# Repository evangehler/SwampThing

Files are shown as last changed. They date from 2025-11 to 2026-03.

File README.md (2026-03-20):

# **SwampThing**
Beginning of a standalone Juno-106 inspired DCO monosynth for UF AES. Built around Raspberry Pi Pico Microcontroller.

## **Project Status**
| Component | Designed  | Prototyped  | PCB / Finalized |
| ----- | ---  | --- | --- |
| DCO Saw-core | X | X | |
| DCO Pulse / PWM | X | X | |
| DCO SUB | X | | |
| Blend | X | | |
| MIDI USB | X | X | |
| MIDI DIN | X | X | |
| VCF | X | X | |
| EG | X | X | |
| VCA | X | X | |
| Power Solution | | | |
| Output | | | |

# Table of Contents
- [Installation / Build](#installation--build)
  - [Prereqs](#prereqs)
  - [Build Steps](#build-steps)
  - [Quick Build & Flash](#quick-build--flash)
  - [Manual Flashing](#manual-flashing)
  - [I/O Notes](#io-notes)
- [Architecture](#architecture)
  - [Component Diagram](#component-diagram)
  - [MIDI](#midi)
    - [USB MIDI](#usb-midi-implemented)
    - [DIN MIDI](#din-midi-planned)
  - [Digitally Controlled Oscillator (DCO)](#digitally-controlled-oscillator-dco)
    - [SAW](#saw)
    - [PULSE / PWM](#pulse--pwm)
    - [SUB OSC](#sub-osc)
    - [BLEND](#blend)
  - [Envelope Generator (EG)](#envelope-generator-eg)
  - [Voltage Controlled Amplifier (VCA)](#voltage-conrolled-amplifier-vca)
  - [Voltage Controlled Filter (VCF)](#voltage-controlled-filter-vcf)
  - [Power Solution](#power-solution)
- [Incomplete BOM](#incomplete-bom)

# Installation / Build
MIDI control, oscillator reset signals, charge voltage and envelope gates are derived from a Raspberry Pi Pico.

### Prereqs
- [VS Code](https://code.visualstudio.com/)
- [Raspberry Pi Pico VS Code Extension](https://marketplace.visualstudio.com/items?itemName=raspberry-pi.raspberry-pi-pico)

### Build Steps
1. Clone this repo
2. Open the `src` folder in VS Code (not the root folder!)
3. Open a PowerShell terminal in VS Code
4. Run:
```powershell
mkdir build
cd build
cmake -G "Ninja" ..
cmake --build .
```
5. The `.uf2` file will be in `build/SwampThing.uf2`

### Quick Build & Flash
- Press `Ctrl+Shift+B` to build and flash in one step - nifty!

### Manual Flashing
1. Hold BOOTSEL on your Pico and plug it in
2. Drag `SwampThing.uf2` onto the Pico drive

### I/O Notes:

| Function | GPIO # | 
| ----- | --- |
| Clock output | 13 |
| CV output | 14 |
| Gate output | 12 |

# Architecture
## Component Diagram:
Component Diagram

## MIDI:

### USB MIDI (Implemented)
SwampThing appears as a **class-compliant USB MIDI device** over the Pico’s micro-USB port using TinyUSB.

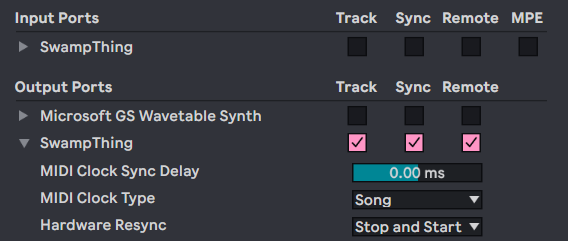
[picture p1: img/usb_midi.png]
USB_MIDI USB MIDI


### DIN MIDI (Planned)

5-pin DIN MIDI IN (with opto-isolation and UART at 31.25 kbps) is planned. DIN and USB MIDI will eventually share the same internal note/gate handling.

## Digitally Controlled Oscillator (DCO):
Basic DCO
### SAW
Juno-style ramp core. A TL074 op-amp integrator generates a rising ramp, NPN transistor reset discharges the timing capacitor at a rate set by the microcontroller clock. Pitch is set by the reset clock (GPIO 13). Ramp slope is set by a PWM-derived charge voltage filtered to DC (GPIO 14).

### PULSE / PWM
Saw --> Comparator, threshold = PWM

### SUB OSC
OSC --> Flip Flop, halves frequency

### BLEND
Blend control between saw and pwm

## Envelope Generator (EG):
*Currently In Development*

Design chosen

## Voltage Conrolled Amplifier (VCA):
*Currently In Development*

JFET implementation

## Voltage Controlled Filter (VCF):
*Currently In Development*

Based on Mortiz Klein / Erica Synths VCF

## Power Solution:
*Currently In Development*

 Presently planning +/- 12V, 5V rails.

 ## Prototype:
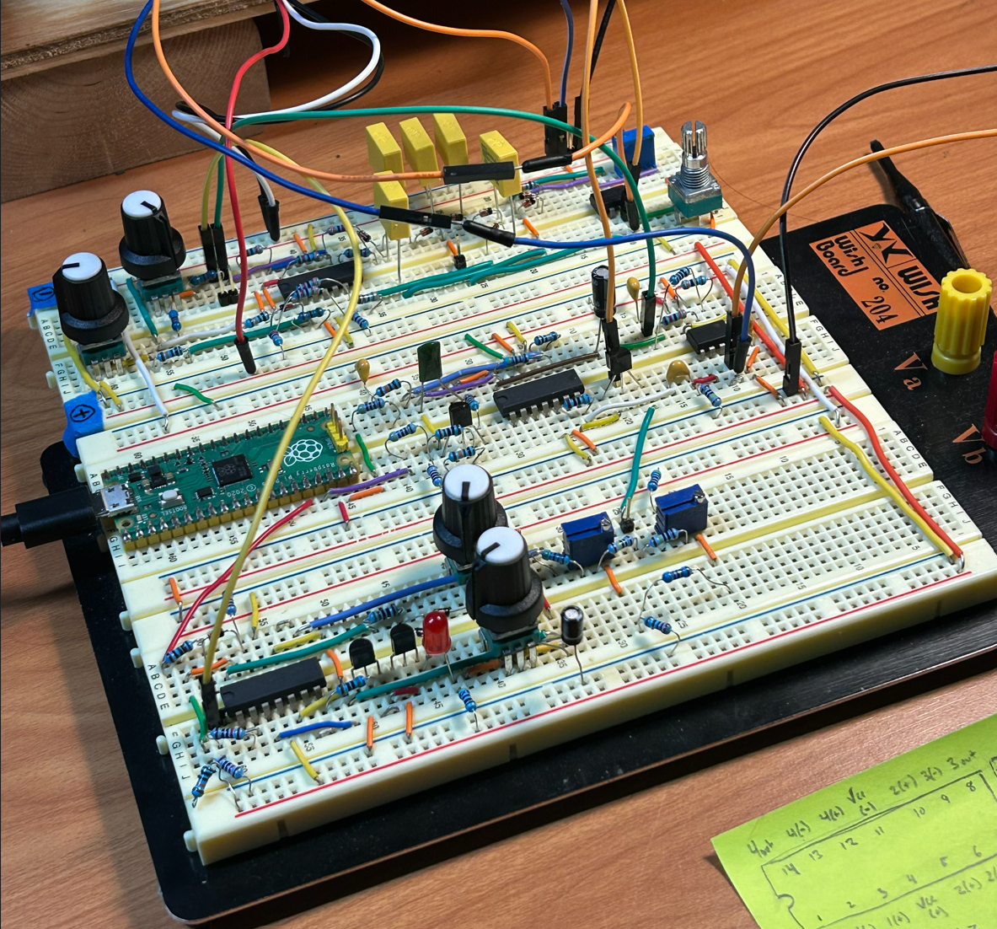
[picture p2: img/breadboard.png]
Prototype


# Incomplete BOM:

| PART | QTY | NOTE |
| ----- | ---  | --- |
| Raspberry Pi Pico | 1 | Micrcontroller |
| TL074 | 1 | 4x Op Amp |
| 2N3904 NPN BJT | 1 | Reset Transistor  |

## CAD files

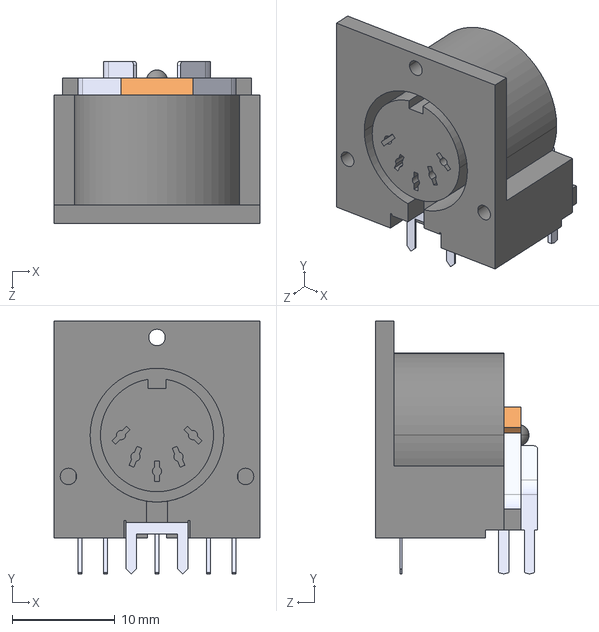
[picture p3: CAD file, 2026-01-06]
sims/Julian_kicad/Swamp_thing_V0/external components/SDS-50J/SDS-50J.step
20.0 x 24.6 x 15.8 mm

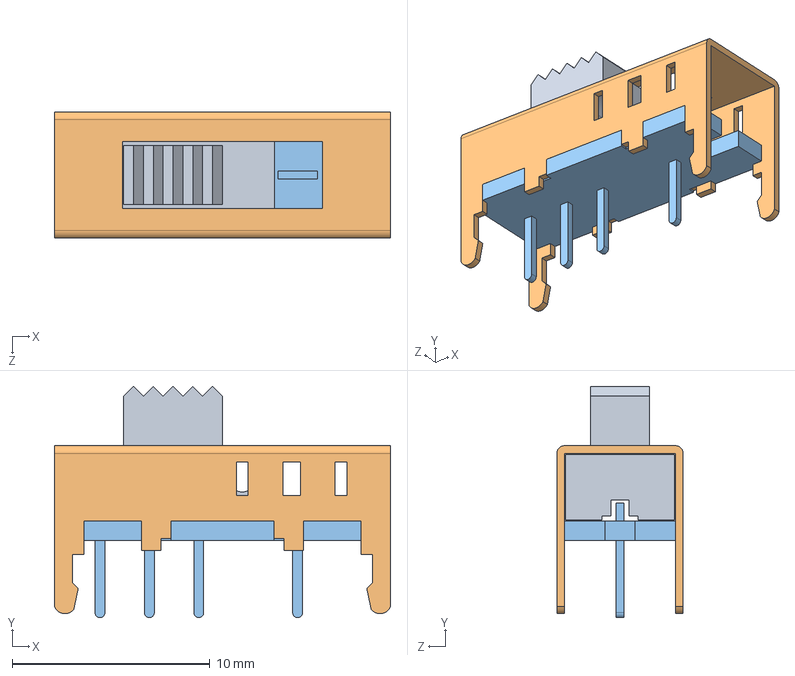
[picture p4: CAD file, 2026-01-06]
sims/Julian_kicad/Swamp_thing_V0/external components/SLW-178562-3A-S-D/SLW-178562-3A-S-D.step
17.0 x 11.7 x 6.40 mm

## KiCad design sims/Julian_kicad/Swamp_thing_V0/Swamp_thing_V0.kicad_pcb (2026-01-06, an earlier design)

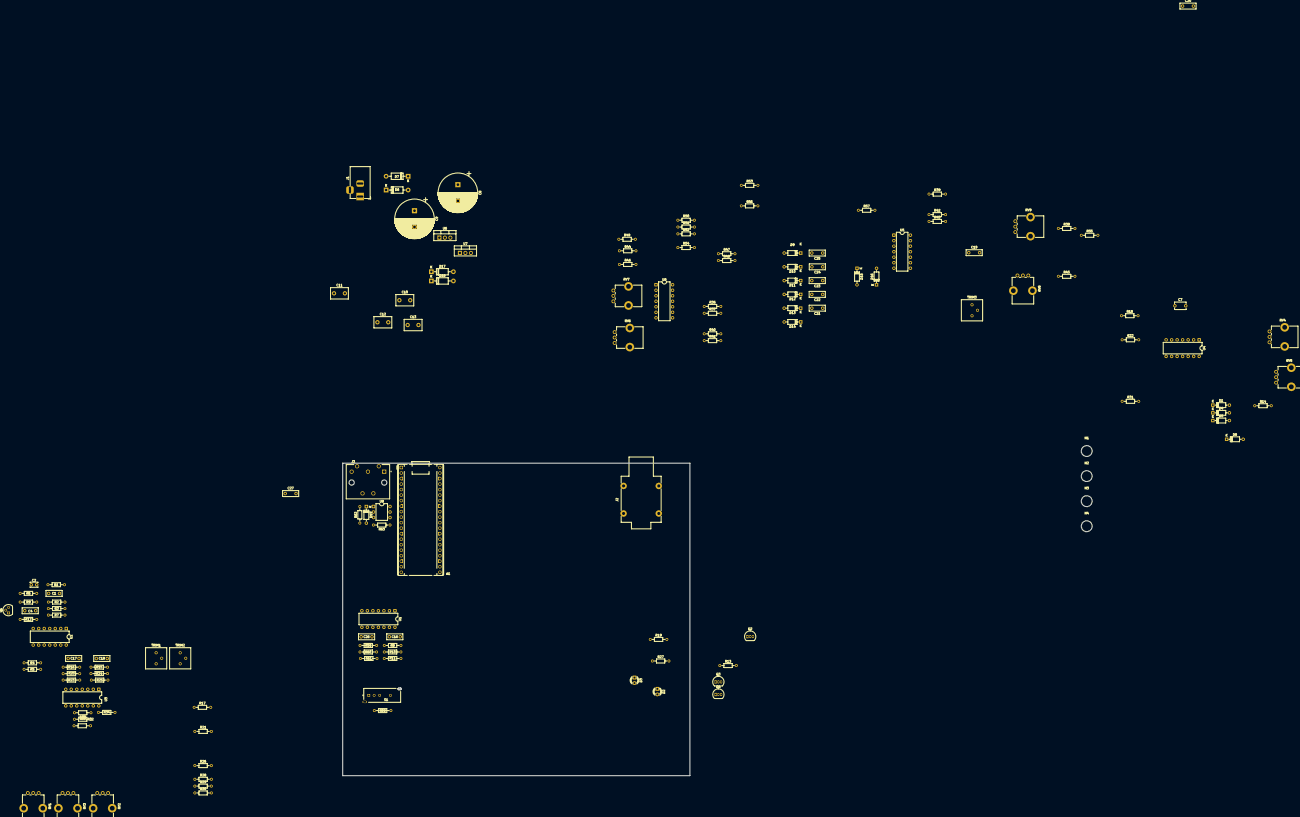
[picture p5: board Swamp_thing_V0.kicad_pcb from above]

Board: 2 copper layers, 160.0 x 144.0 mm, 138 parts (0 on the bottom side), 107 nets, no tracks yet.

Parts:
A1: RaspberryPi_Pico; RaspberryPi_Pico_Common_THT
C1, C16, C17, C18, C19, C20, C26, C27: 100n; C_Rect_L7.2mm_W2.5mm_P5.00mm_FKS2_FKP2_MKS2_MKP2
C2: 470pF; C_Disc_D3.4mm_W2.1mm_P2.50mm
C4, C21, C22, C23, C24, C25: 1n; C_Rect_L7.2mm_W2.5mm_P5.00mm_FKS2_FKP2_MKS2_MKP2
C7: C; C_Disc_D5.1mm_W3.2mm_P5.00mm
C8, C9: 3300uF; CP_Radial_D18.0mm_P7.50mm
C10, C11, C12, C13: C; C_Disc_D8.0mm_W5.0mm_P5.00mm
D1, D4, D5, D8, D9, D10, D11, D12, D13, D14, D15, D16, D19: 1N4148; D_DO-35_SOD27_P7.62mm_Horizontal
D2, D3: LED; LED_D3.0mm
D6, D7, D17, D18: 1N4007; D_DO-41_SOD81_P10.16mm_Horizontal
H1, H2, H3, H4: MountingHole; MountingHole_5mm
J1: Barrel_Jack_MountingPin; BarrelJack_Horizontal
J2: NMJ4HFD2; Jack_6.35mm_Neutrik_NMJ4HFD2_Horizontal
J3: SDS-50J; CUI_SDS-50J
Q1: 2N3904; TO-92
Q2, Q3, Q4: 2N3904; TO-92_Inline
R1, R2, R3, R4, R5, R6, R7, R8, R9, R10, R11, R12, R13, R14, R15, R16, R17, R18, R19, R20, R21, R22, R23, R24, R25, R26, R27, R28, R29, R30, R31, R32, R33, R34, R35, R36, R37, R38, R39, R40, R41, R42, R43, R44, R45, R46, R47, R48, R49, R50, R51, R52, R53, R54, R55, R56, R57, R58, R59, R60, R61: R_US; R_Axial_DIN0204_L3.6mm_D1.6mm_P7.62mm_Horizontal
R62: 220; R_Axial_DIN0204_L3.6mm_D1.6mm_P7.62mm_Horizontal
R63: 180; R_Axial_DIN0204_L3.6mm_D1.6mm_P7.62mm_Horizontal
RV1: PWM; Potentiometer_Bourns_PTV09A-1_Single_Vertical
RV2: BLEND; Potentiometer_Bourns_PTV09A-1_Single_Vertical
RV3: SUB VOL; Potentiometer_Bourns_PTV09A-1_Single_Vertical
RV4: ATTACK; Potentiometer_Bourns_PTV09A-1_Single_Vertical
RV5: RELEASE; Potentiometer_Bourns_PTV09A-1_Single_Vertical
RV6: FILTER; Potentiometer_Bourns_PTV09A-1_Single_Vertical
RV7: FILTER EG; Potentiometer_Bourns_PTV09A-1_Single_Vertical
RV8: VOLUME; Potentiometer_Bourns_PTV09A-1_Single_Vertical
RV9: RESO; Potentiometer_Bourns_PTV09A-1_Single_Vertical
S1: SLW-178562-3A-S-D; SW_SLW-178562-3A-S-D
TRIM1, TRIM2, TRIM3: R_Potentiometer_Trim_US; Potentiometer_Bourns_3386P_Vertical
U1: 4013; DIP-14_W7.62mm
U2, U3, U4, U5, U8: TL074; DIP-14_W7.62mm
U6: L7812; TO-220-3_Vertical
U7: L7912; TO-220-3_Vertical
U9: H11L1; DIP-6_W7.62mm

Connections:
+3V3: A1.36 (3V3), R63.2, U9.6
+12V: C11.2, D17.2 (A), R4.1, R18.2, R19.2, R27.2, RV6.1, U1.14 (VDD), U2.4 (V+), U3.4 (V+), U4.4 (V+), U5.4 (V+), U6.3 (OUT), U8.4 (V+)
-12V: C13.1, D18.1 (K), R28.2, R36.1, R46.1, U2.11 (V-), U3.11 (V-), U4.11 (V-), U5.11 (V-), U7.3 (VO), U8.11 (V-)
/CLK: A1.19 (GPIO14), C2.2
/Charge PWM: A1.20 (GPIO15), R1.2
/EG_TO_LED: R13.2, U4.8, U4.9 (-)
/EG_TO_VCA: R17.2, U4.13 (-), U4.14
/EG_TO_VCF: R37.2, U4.6 (-), U4.7
/FILTER_FB: C21.1, C25.1, D15.2 (A), D16.1 (K), R57.2, U5.7
/JFET_BIAS: R21.1, R26.2
/MIDI_DIN_IN: R63.1, U9.4
/N_SUB-1: U1.2 (~Q), U1.5 (D)
/N_SUB-2: U1.9 (D), U1.12 (~Q)
/PULSE: C17.1, U2.8
/SAW: C4.2, C18.1, R12.1, U2.7, U2.9 (-)
/SUB: RV3.1, RV3.2, U2.13 (-), U2.14
/SUB-1: C26.1, U1.1 (Q), U1.11 (C)
/SUB-2: C16.1, U1.13 (Q)
/VCA_OUT: C19.1, R34.2, U3.14
/VCF_AUDIO: R47.2, R50.1, U8.1, U8.2 (-)
/VCF_BIAS: D8.1 (K), R46.2, R48.2, R49.1, R51.1
/VCF_OUT: R38.1, RV9.3, U5.1, U5.2 (-)
GND: A1.3 (GND), A1.8 (GND), A1.13 (GND), A1.18 (GND), A1.23 (GND), A1.28 (GND), A1.38 (GND), C1.2, C7.2, C8.2, C9.1, C10.1, C11.1, C12.2, C13.2, C22.1, C23.1, C24.1, C27.1, J1.2, J2.S, Q2.1 (E), Q3.1 (E), Q4.1 (E), R5.2, R6.1, R11.1, R22.2, R23.1, R25.2, R30.1, R43.1, R45.2, R49.2, R52.2, R59.2, R61.1, RV7.3, U1.4 (R), U1.6 (S), U1.7 (VSS), U1.8 (S), U1.10 (R), U2.3 (+), U2.5 (+), U3.10 (+), U3.12 (+), U5.10 (+), U6.2 (GND), U7.1 (GND), U8.5 (+), U8.10 (+), U9.5
unnamed: C1.1, R1.1, R2.2
unnamed: C2.1, R6.2, R9.2
unnamed: C16.2, R8.2
unnamed: C17.2, R16.2
unnamed: C18.2, R15.2
unnamed: C19.2, R39.2
unnamed: C20.1, RV8.2, RV8.3, U5.8
unnamed: C26.2, R58.2
unnamed: C27.2, J3.2
unnamed: D1.2 (A), R14.1
unnamed: D1.1 (K), U4.3 (+)
unnamed: D2.2 (A), R19.1
unnamed: D2.1 (K), Q3.3 (C)
unnamed: D3.2 (A), R27.1
unnamed: D3.1 (K), Q4.3 (C)
unnamed: D4.2 (A), D5.1 (K), R31.1
unnamed: D4.1 (K), RV4.3
unnamed: D5.2 (A), RV5.3
unnamed: D6.1 (K), D7.2 (A), J1.1
unnamed: D8.2 (A), R44.2, U8.7
unnamed: D9.2 (A), R53.1, R56.2
unnamed: C25.2, D9.1 (K), D10.2 (A)
unnamed: C24.2, D10.1 (K), D11.2 (A)
unnamed: C23.2, D11.1 (K), D12.2 (A), U5.3 (+)
unnamed: C22.2, D12.1 (K), D13.2 (A)
unnamed: C21.2, D13.1 (K), D14.2 (A)
unnamed: D14.1 (K), R54.2, U8.14
unnamed: D15.1 (K), D16.2 (A), R57.1, TRIM3.1, TRIM3.2, U5.6 (-)
unnamed: C8.1, C10.2, D7.1 (K), D17.1 (K), U6.1 (IN)
unnamed: C9.2, C12.1, D6.2 (A), D18.2 (A), U7.2 (VI)
unnamed: D19.2 (A), R62.1, U9.2
unnamed: D19.1 (K), J3.4, U9.1
unnamed: J2.T, R55.2
unnamed: J3.5, R62.2
unnamed: Q1.2 (B), R9.1
unnamed: Q1.3 (C), R12.2
unnamed: C4.1, Q1.1 (E), R7.1, U2.6 (-)
unnamed: Q2.2 (B), Q2.3 (C), Q3.2 (B), Q4.2 (B), R13.1
unnamed: R34.1, U3.13 (-)
unnamed: R3.1, R7.2, U2.1
unnamed: R4.2, RV1.1
unnamed: R5.1, RV1.3
unnamed: R10.1, R11.2
unnamed: R8.1, R10.2, S1.4
unnamed: R16.1, R20.2
unnamed: R17.1, TRIM1.1
unnamed: R21.2, TRIM1.2
unnamed: R24.2, R25.1
unnamed: R26.1, TRIM2.2
unnamed: R28.1, TRIM2.1
unnamed: R29.1, R30.2, TRIM1.3
unnamed: R29.2, TRIM2.3
unnamed: R31.2, U4.1
unnamed: R32.2, RV2.2
unnamed: R33.2, RV3.3
unnamed: R36.2, RV6.3
unnamed: R37.1, RV7.1
unnamed: R39.1, R42.2
unnamed: R40.1, RV6.2
unnamed: R41.1, RV7.2
unnamed: R56.1, U8.8
unnamed: R58.1, R60.2, S1.1
unnamed: R59.1, S1.2
unnamed: R60.1, R61.2
unnamed: RV9.1, TRIM3.3
unnamed: R2.1, R3.2, U2.2 (-)
unnamed: RV1.2, U2.10 (+)
unnamed: S1.3, U2.12 (+)
unnamed: R15.1, R24.1, U3.3 (+)
unnamed: RV2.1, U3.1, U3.2 (-)
unnamed: R20.1, R23.2, U3.5 (+)
unnamed: RV2.3, U3.6 (-), U3.7
unnamed: R32.1, R33.1, R35.2, U3.9 (-)
unnamed: R18.1, R22.1, U4.2 (-)
unnamed: C7.1, RV4.1, RV4.2, RV5.1, RV5.2, U4.5 (+), U4.10 (+), U4.12 (+)
unnamed: RV9.2, U5.5 (+)
unnamed: R38.2, RV8.1, U5.9 (-)
unnamed: C20.2, R45.1, U5.12 (+)
unnamed: R55.1, U5.13 (-), U5.14
unnamed: R42.1, R43.2, U8.3 (+)
unnamed: R40.2, R41.2, R44.1, U8.6 (-)
unnamed: R47.1, R48.1, R53.2, U8.9 (-)
unnamed: R51.2, R52.1, U8.12 (+)
unnamed: R50.2, R54.1, U8.13 (-)

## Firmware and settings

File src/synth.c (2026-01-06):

#include "synth.h"
#include "pico/stdlib.h"
#include "hardware/pwm.h"

// ---------------- Pins ----------------
#define CLOCK_PIN 13
#define CV_PIN    14
#define GATE_PIN  12

// ---------------- Clocks/rails ----------------
#define SYS_CLK_HZ 125000000.0f
#define V_SUPPLY   3.3f
#define V_SUPPLY_INV (1.0f / V_SUPPLY)

// ---------------- Clocked-reset DCO model ----------------
#define CLOCK_DIV     150.0f
#define CLOCK_DIV_INV (1.0f / CLOCK_DIV)
#define RESET_US      9.0f

// Pre-compute tick rate and reset pulse width
#define TICK_HZ       (SYS_CLK_HZ * CLOCK_DIV_INV)
#define RESET_TICKS   ((uint32_t)(TICK_HZ * RESET_US * 1e-6f + 0.5f))

// CV mapping
#define MV_PER_HZ     0.000060f
#define CV_GAIN       10.0f
#define CV_OFFSET     0.0f

// CV PWM carrier
#define CV_PWM_CARRIER_HZ 500000u

// Frequency limits
#define FREQ_MIN      10.0f
#define FREQ_MAX      20000.0f

// ---------------- Static state ----------------
static uint clk_slice, clk_chan;
static uint cv_slice,  cv_chan;
static uint32_t cv_wrap = 0;

void synth_init(void) {
    // ----- RESET CLOCK PWM -----
    gpio_set_function(CLOCK_PIN, GPIO_FUNC_PWM);
    clk_slice = pwm_gpio_to_slice_num(CLOCK_PIN);
    clk_chan  = pwm_gpio_to_channel(CLOCK_PIN);

    pwm_config clk_cfg = pwm_get_default_config();
    pwm_config_set_clkdiv(&clk_cfg, CLOCK_DIV);
    pwm_config_set_wrap(&clk_cfg, 60000);
    pwm_init(clk_slice, &clk_cfg, true);
    pwm_set_chan_level(clk_slice, clk_chan, 1);

    // ----- CV PWM -----
    gpio_set_function(CV_PIN, GPIO_FUNC_PWM);
    cv_slice = pwm_gpio_to_slice_num(CV_PIN);
    cv_chan  = pwm_gpio_to_channel(CV_PIN);

    // Compute wrap for carrier frequency
    cv_wrap = (uint32_t)(SYS_CLK_HZ / CV_PWM_CARRIER_HZ) - 1;

    pwm_config cv_cfg = pwm_get_default_config();
    pwm_config_set_clkdiv(&cv_cfg, 1.0f);
    pwm_config_set_wrap(&cv_cfg, cv_wrap);
    pwm_init(cv_slice, &cv_cfg, true);
    pwm_set_chan_level(cv_slice, cv_chan, 0);

    // ----- GATE -----
    gpio_init(GATE_PIN);
    gpio_set_dir(GATE_PIN, GPIO_OUT);
    gpio_put(GATE_PIN, 0);
}

void synth_set_frequency(float freq_hz) {
    // Clamp frequency
    if (freq_hz < FREQ_MIN) freq_hz = FREQ_MIN;
    else if (freq_hz > FREQ_MAX) freq_hz = FREQ_MAX;

    // ---------- RESET CLOCK ----------
    float wrap_f = (SYS_CLK_HZ * CLOCK_DIV_INV / freq_hz) - 1.0f;
    
    // Clamp wrap value
    if (wrap_f < 1.0f) wrap_f = 1.0f;
    else if (wrap_f > 65535.0f) wrap_f = 65535.0f;
    
    uint16_t wrap = (uint16_t)(wrap_f + 0.5f);
    pwm_set_wrap(clk_slice, wrap);

    // ---------- RESET PULSE ----------
    // Using pre-computed constant, clamp to wrap
    uint32_t pulse = (RESET_TICKS > wrap) ? wrap : RESET_TICKS;
    pwm_set_chan_level(clk_slice, clk_chan, pulse);

    // ---------- CV ----------
    float v_cv = (freq_hz * MV_PER_HZ) * CV_GAIN + CV_OFFSET;
    
    // Clamp voltage
    if (v_cv < 0.0f) v_cv = 0.0f;
    else if (v_cv > V_SUPPLY) v_cv = V_SUPPLY;

    // Convert to PWM level
    uint32_t level = (uint32_t)(v_cv * V_SUPPLY_INV * (cv_wrap + 1) + 0.5f);
    if (level > cv_wrap) level = cv_wrap;

    pwm_set_chan_level(cv_slice, cv_chan, level);
}

void synth_gate_on(void) {
    gpio_put(GATE_PIN, 1);
}

void synth_gate_off(void) {
    gpio_put(GATE_PIN, 0);
}

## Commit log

2025-11-26 USB MIDI support
    [swampthing.kicad_sch]
2025-11-26 significant pitch tracking improvement
2025-11-26 LED MIDI Flash
2026-01-05 Creating a directoy for my kicad project so you guys have it
2026-01-05 KiCad WIP
    [SDS-50J.step, SLW-178562-3A-S-D.step, Swamp_thing_V0.kicad_pcb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]
2026-01-06 Updated circuit / firmware so that reset pulse is sent via pico PWM rather than filtered clock
    [swampthing.kicad_sch]
